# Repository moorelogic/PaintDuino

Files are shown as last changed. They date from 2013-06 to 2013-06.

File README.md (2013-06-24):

# PaintDuino

## Introduction
The PaintDuino is an Arduino Leonardo compatible, universal paintball marker control board.

PaintDuino Board

### Features:
* Easily programmed with Arduino IDE
* Interface for 128 x 32 OLED display
* Two high current solenoid drivers
* RGB LED for status and trigger programming
* Supports both switched and push button On/Off
* USB Mini B programming connector
* Near zero battery drain when powered off

## License
This work is licensed under a Creative Commons Attribution-ShareAlike 3.0 Unported License.

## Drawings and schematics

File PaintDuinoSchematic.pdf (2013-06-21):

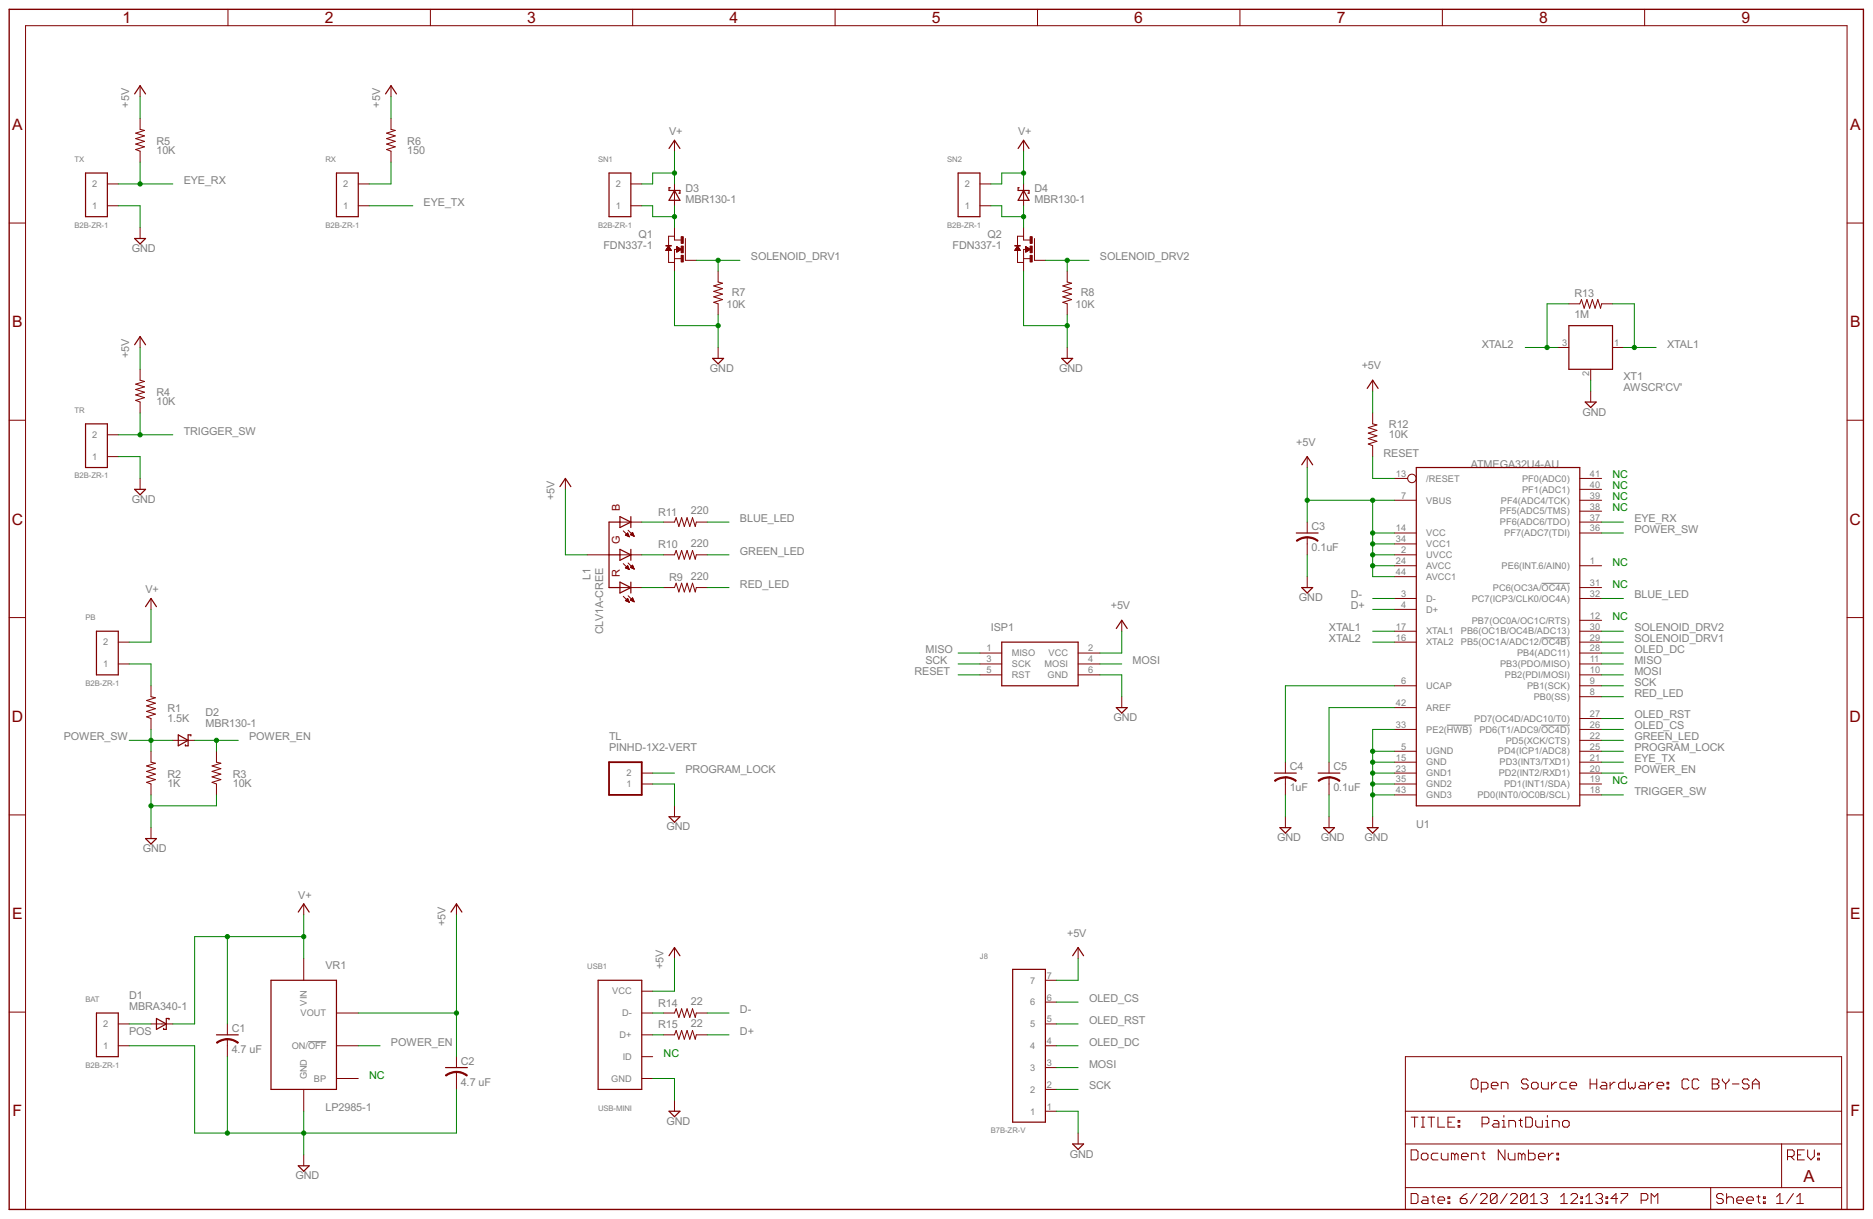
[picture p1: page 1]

VR1 VIN GND ON/OFFBP

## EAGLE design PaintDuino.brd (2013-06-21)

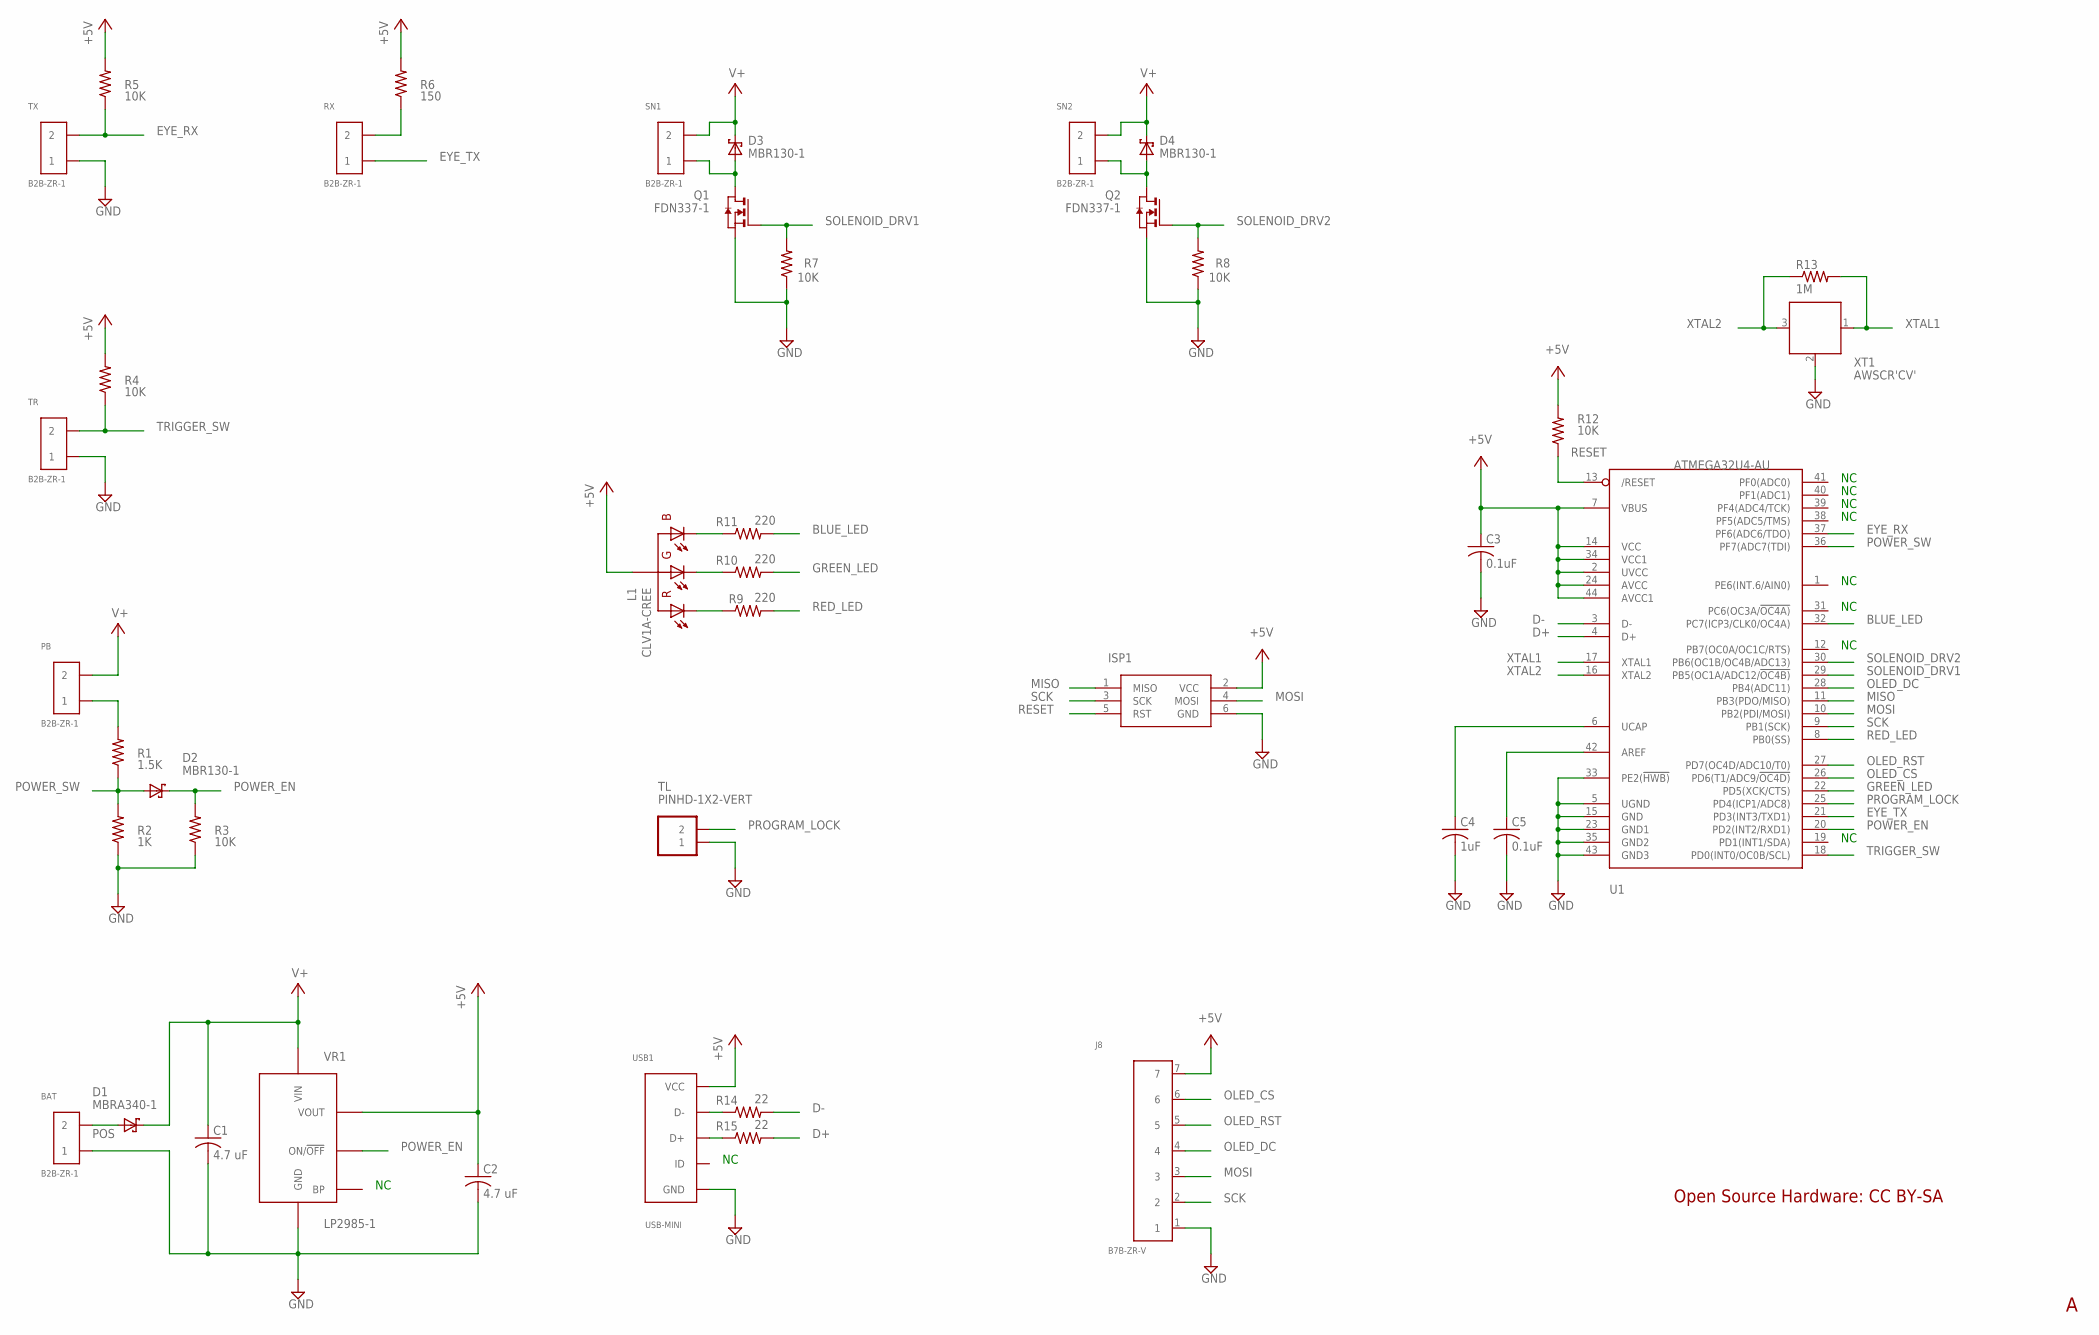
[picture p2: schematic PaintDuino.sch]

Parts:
BAT: B2B-ZR-1; B2B-ZR
C1, C2: 4.7 uF; C0805
C3, C5: 0.1uF; C0805
C4: 1uF; C0805
D1: MBRA340-1; DO214AC
D2, D3, D4: MBR130-1; SOD123
ISP1: AVRISP-6; AVRISP
J8: B7B-ZR-V; B7B-ZR
L1: CLV1A-CREE; PLCC4
PB: B2B-ZR-1; B2B-ZR
Q1, Q2: FDN337-1; SOT23
R1: 1.5K; R0805
R2: 1K; R0805
R3, R4, R5, R7, R8, R12: 10K; R0805
R6: 150; R0805
R9, R10, R11: 220; R0805
R13: 1M; R0805
R14, R15: 22; R0805
RX: B2B-ZR-1; B2B-ZR
SN1, SN2: B2B-ZR-1; B2B-ZR
TL: PINHD-1X2-VERT; 1X02
TR: B2B-ZR-1; B2B-ZR
TX: B2B-ZR-1; B2B-ZR
U1: ATMEGA32U4-AU; TQFP44
USB1: USB-MINI; USB-M2
VR1: LP2985-1; SOT23-5
XT1: AWSCR'CV'; AWSCR-CV

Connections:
+5V: C2.1, C3.1, ISP1.2 (VCC), J8.7, L1.2-CA (A), R4.2, R5.2, R6.2, R12.2, U1.2 (UVCC), U1.7 (VBUS), U1.14 (VCC), U1.24 (AVCC), U1.34 (VCC1), U1.44 (AVCC1), USB1.1 (VCC), VR1.5 (VOUT)
AREF: C5.1, U1.42 (AREF)
BC: L1.3-B (BC), R11.1
BLUE_LED: R11.2, U1.32 (PC7(ICP3/CLK0/OC4A))
D+: R15.2, U1.4 (D+)
D-: R14.2, U1.3 (D-)
EYE_C: R6.1, RX.2
EYE_RX: R5.1, TX.2, U1.37 (PF6(ADC6/TDO))
EYE_TX: RX.1, U1.21 (PD3(INT3/TXD1))
GC: L1.4-G (GC), R10.1
GND: BAT.1, C1.2, C2.2, C3.2, C4.2, C5.2, ISP1.6 (GND), J8.1, Q1.2 (S), Q2.2 (S), R2.1, R3.1, R7.1, R8.1, TL.1, TR.1, TX.1, U1.5 (UGND), U1.15 (GND), U1.23 (GND1), U1.33 (PE2(!HWB)), U1.35 (GND2), U1.43 (GND3), USB1.5 (GND), VR1.2 (GND), XT1.2
GREEN_LED: R10.2, U1.22 (PD5(XCK/CTS))
MISO: ISP1.1 (MISO), U1.11 (PB3(PDO/MISO))
MOSI: ISP1.4 (MOSI), J8.3, U1.10 (PB2(PDI/MOSI))
unnamed: R14.1, USB1.2 (D-)
unnamed: R15.1, USB1.3 (D+)
OLED_CS: J8.6, U1.26 (PD6(T1/ADC9/!OC4D))
OLED_DC: J8.4, U1.28 (PB4(ADC11))
OLED_RST: J8.5, U1.27 (PD7(OC4D/ADC10/T0))
PB: PB.1, R1.2
POS: BAT.2, D1.A
POWER_EN: D2.C, R3.2, U1.20 (PD2(INT2/RXD1)), VR1.3 (ON/!OFF)
POWER_SW: D2.A, R1.1, R2.2, U1.36 (PF7(ADC7(TDI))
PROGRAM_LOCK: TL.2, U1.25 (PD4(ICP1/ADC8))
Q1_D: D3.A, Q1.3 (D), SN1.1
Q2_D: D4.A, Q2.3 (D), SN2.1
RC: L1.1-R (RC), R9.1
RED_LED: R9.2, U1.8 (PB0(SS))
RESET: ISP1.5 (RST), R12.1, U1.13 (/RESET)
SCK: ISP1.3 (SCK), J8.2, U1.9 (PB1(SCK))
SOLENOID_DRV1: Q1.1 (G), R7.2, U1.29 (PB5(OC1A/ADC12/!OC4B))
SOLENOID_DRV2: Q2.1 (G), R8.2, U1.30 (PB6(OC1B/OC4B/ADC13))
TRIGGER_SW: R4.1, TR.2, U1.18 (PD0(INT0/OC0B/SCL))
UCAP: C4.1, U1.6 (UCAP)
V+: C1.1, D1.C, D3.C, D4.C, PB.2, SN1.2, SN2.2, VR1.1 (VIN)
XTAL1: R13.2, U1.17 (XTAL1), XT1.1
XTAL2: R13.1, U1.16 (XTAL2), XT1.3

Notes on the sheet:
Open Source Hardware: CC BY-SA

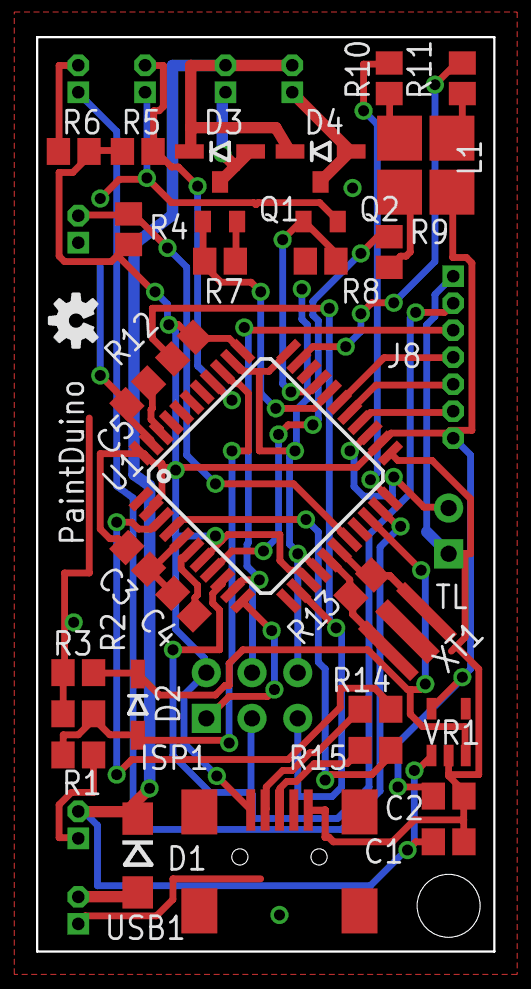
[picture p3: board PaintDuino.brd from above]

Board: 2 copper layers, 25.4 x 50.8 mm, 42 parts (0 on the bottom side), 37 nets.

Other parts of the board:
U$1: OSHW-LOGO-S

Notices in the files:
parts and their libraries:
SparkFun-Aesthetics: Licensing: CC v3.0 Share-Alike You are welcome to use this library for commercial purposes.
